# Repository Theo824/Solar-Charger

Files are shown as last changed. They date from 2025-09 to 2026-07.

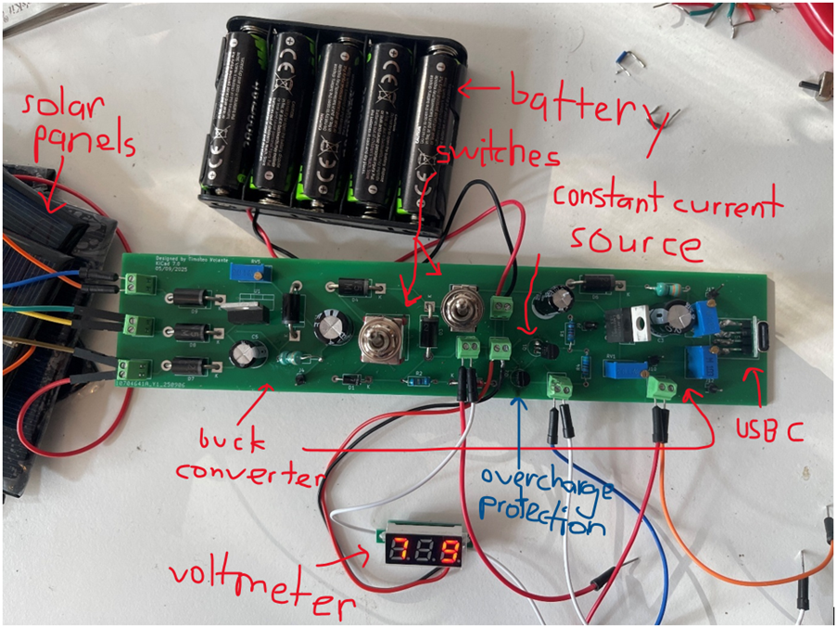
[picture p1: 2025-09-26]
PCB_Pics/solarCharger_assembled_PCB_diagramPic.png

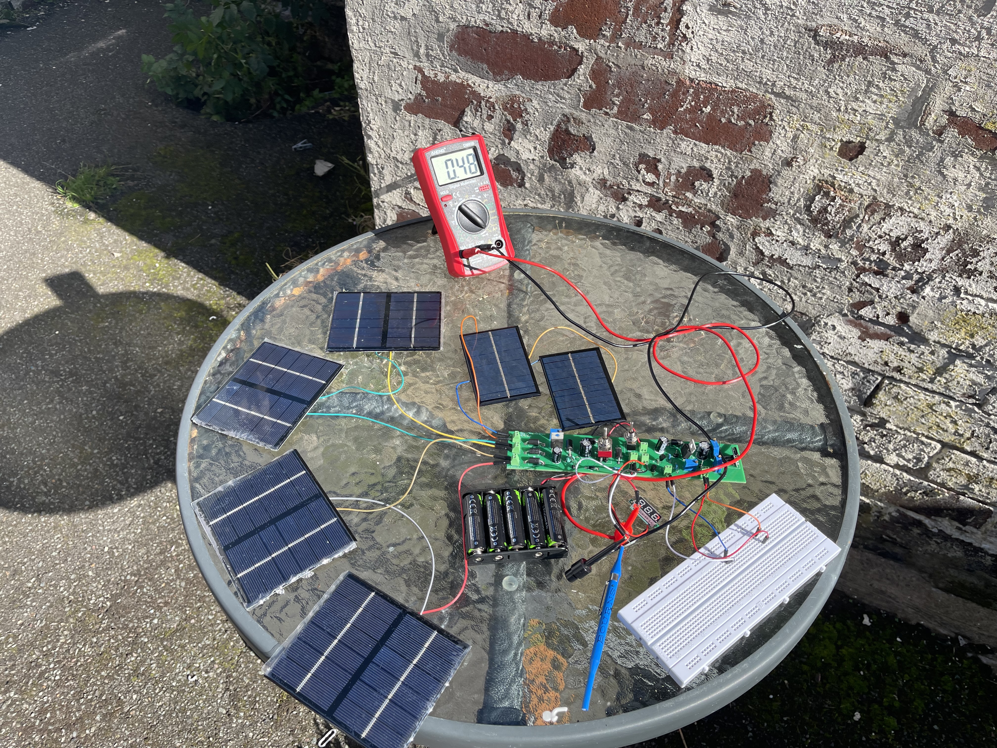
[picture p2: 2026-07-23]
Testing_Pics/NiMHBatteryCharging.jpg

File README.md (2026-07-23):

Designed and built a solar panel-powered constant-current charger for NiMH or NiCD batteries, or an iPhone, 
which can function as a power bank or be used in other devices.

The voltages are adjustable to accommodate any battery, and the solar panels are detachable through screw connectors.

Conceived the design concept centred around only two transistors. 
Researched the iPhone charging handshake protocol, modified the circuit in NI Multisim to correct functionality, 
and integrated it onto a 2-layer PCB using KiCad.

The charger delivered 5 W to the iPhone and 4 W to five AA NiMH batteries in series.
Once fully charged, the auto-cutoff reduced the charging current by 85.12% to 0.025C. 

In theory, the batteries could also charge an iPhone 12 Pro Max up to three times without the solar panels.

The LED display shows the battery voltage. 
To turn it to iPhone charging, turn the switches down; for NiMH charging, turn them up.

For more step-by-step information on the process or log of making this project, please look at solarCharger24-25_Logbook.pdf or solarCharger24-25_Logbook.docx: [Click here to view the Cloud File](https://1drv.ms/w/c/10176ce2d1328c94/IQDAm-Wb3D2zQ42p3uI7dwKKAQNEjcbpd-CYOFzZ3OIuXmA?e=BsMwEE)

Note: The descriptions are below their corresponding images.

sketchIdea

clearKiCadSchematic

solarChargerPCB_diagramPic

The PCB could be made significantly smaller by using smaller components, switching to surface-mount devices, 
and removing test components such as screw connectors. 

I did not use surface-mount devices because my inexpensive soldering kit cannot solder them precisely. 
Using only one buck converter is not feasible, since a 5 V output cannot charge 5 × AA NiMH batteries (5–7 V), 
lower battery voltages cannot charge an iPhone, and using more than 5 V with a single buck converter would damage the iPhone.

KiCadPic

KiCadPic3D

breadboardTest_iPhone

If you look closely, you can see the iPhone lightning symbol, which indicates charging. 
The power adapter could not give more than 0.53 A.



The graph above is the data gathered from testing the breadboard prototype on charging NiMH battery.
It indicates auto-cutoff at 7.25 V or 1.45 V each battery cell.

NiMHBatteryCharging

0.48 A is the charging current of the NiMH battery.

NiMH_PCB_CutOff

The graph above is the data gathered from testing the PCB prototype on charging NiMH battery. 
It indicates auto-cutoff at 7.33 V or 1.466 V each battery cell.

iPhone5WCharg

0.83 A is the recorded charging current of iPhone. This fluctuated around 1 A (5 W) throughout the testing.

iPhoneChargeGraph1

The graph above illustrates the charging speed in relation to the battery percentage. It roughly takes 5 minutes to increase it by 1%.

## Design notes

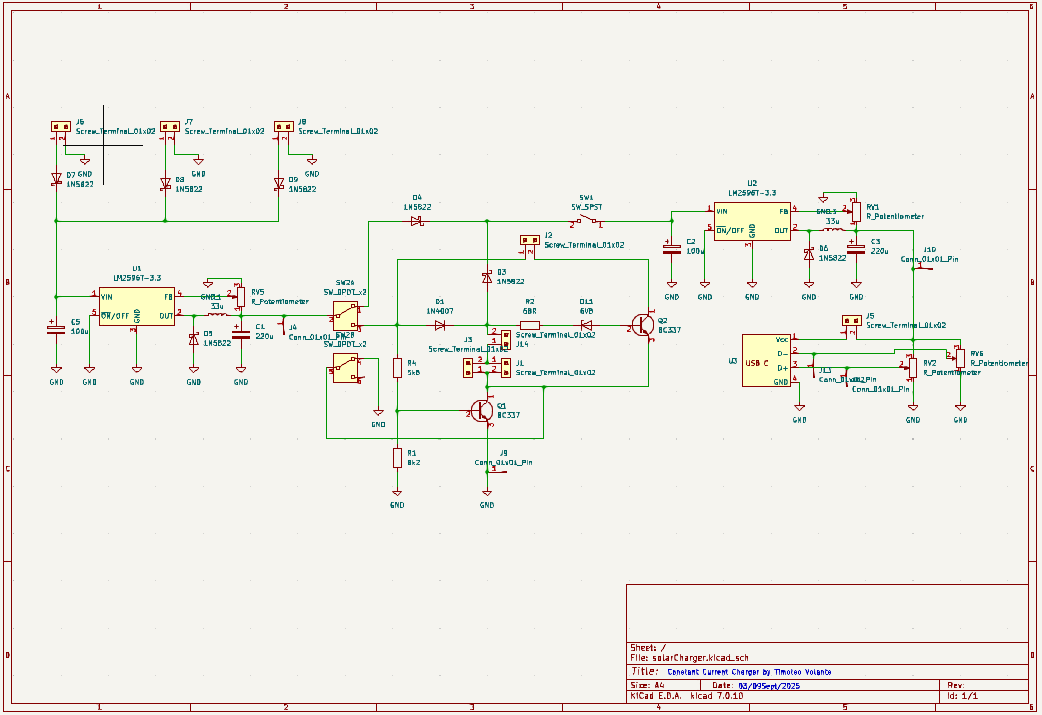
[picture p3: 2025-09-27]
PCB_Pics/clearKiCadSchematic.png

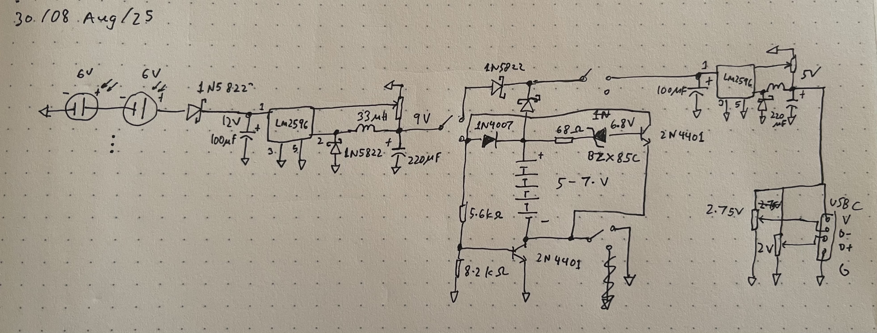
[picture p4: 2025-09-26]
PCB_Pics/sketchIdea.jpg

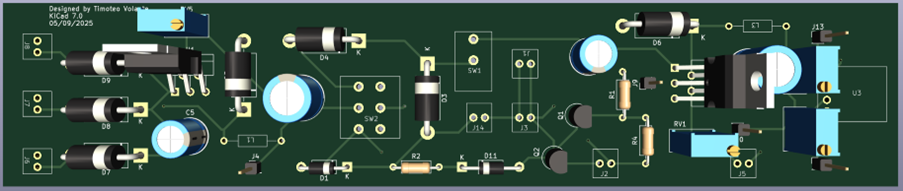
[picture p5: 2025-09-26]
PCB_Pics/KiCad_3D_Model_Pic.png

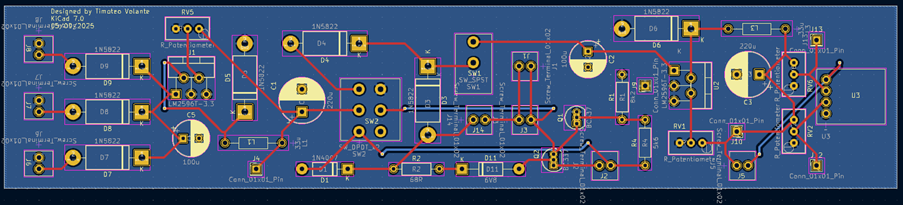
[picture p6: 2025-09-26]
PCB_Pics/KiCad_Layers_Pic.png

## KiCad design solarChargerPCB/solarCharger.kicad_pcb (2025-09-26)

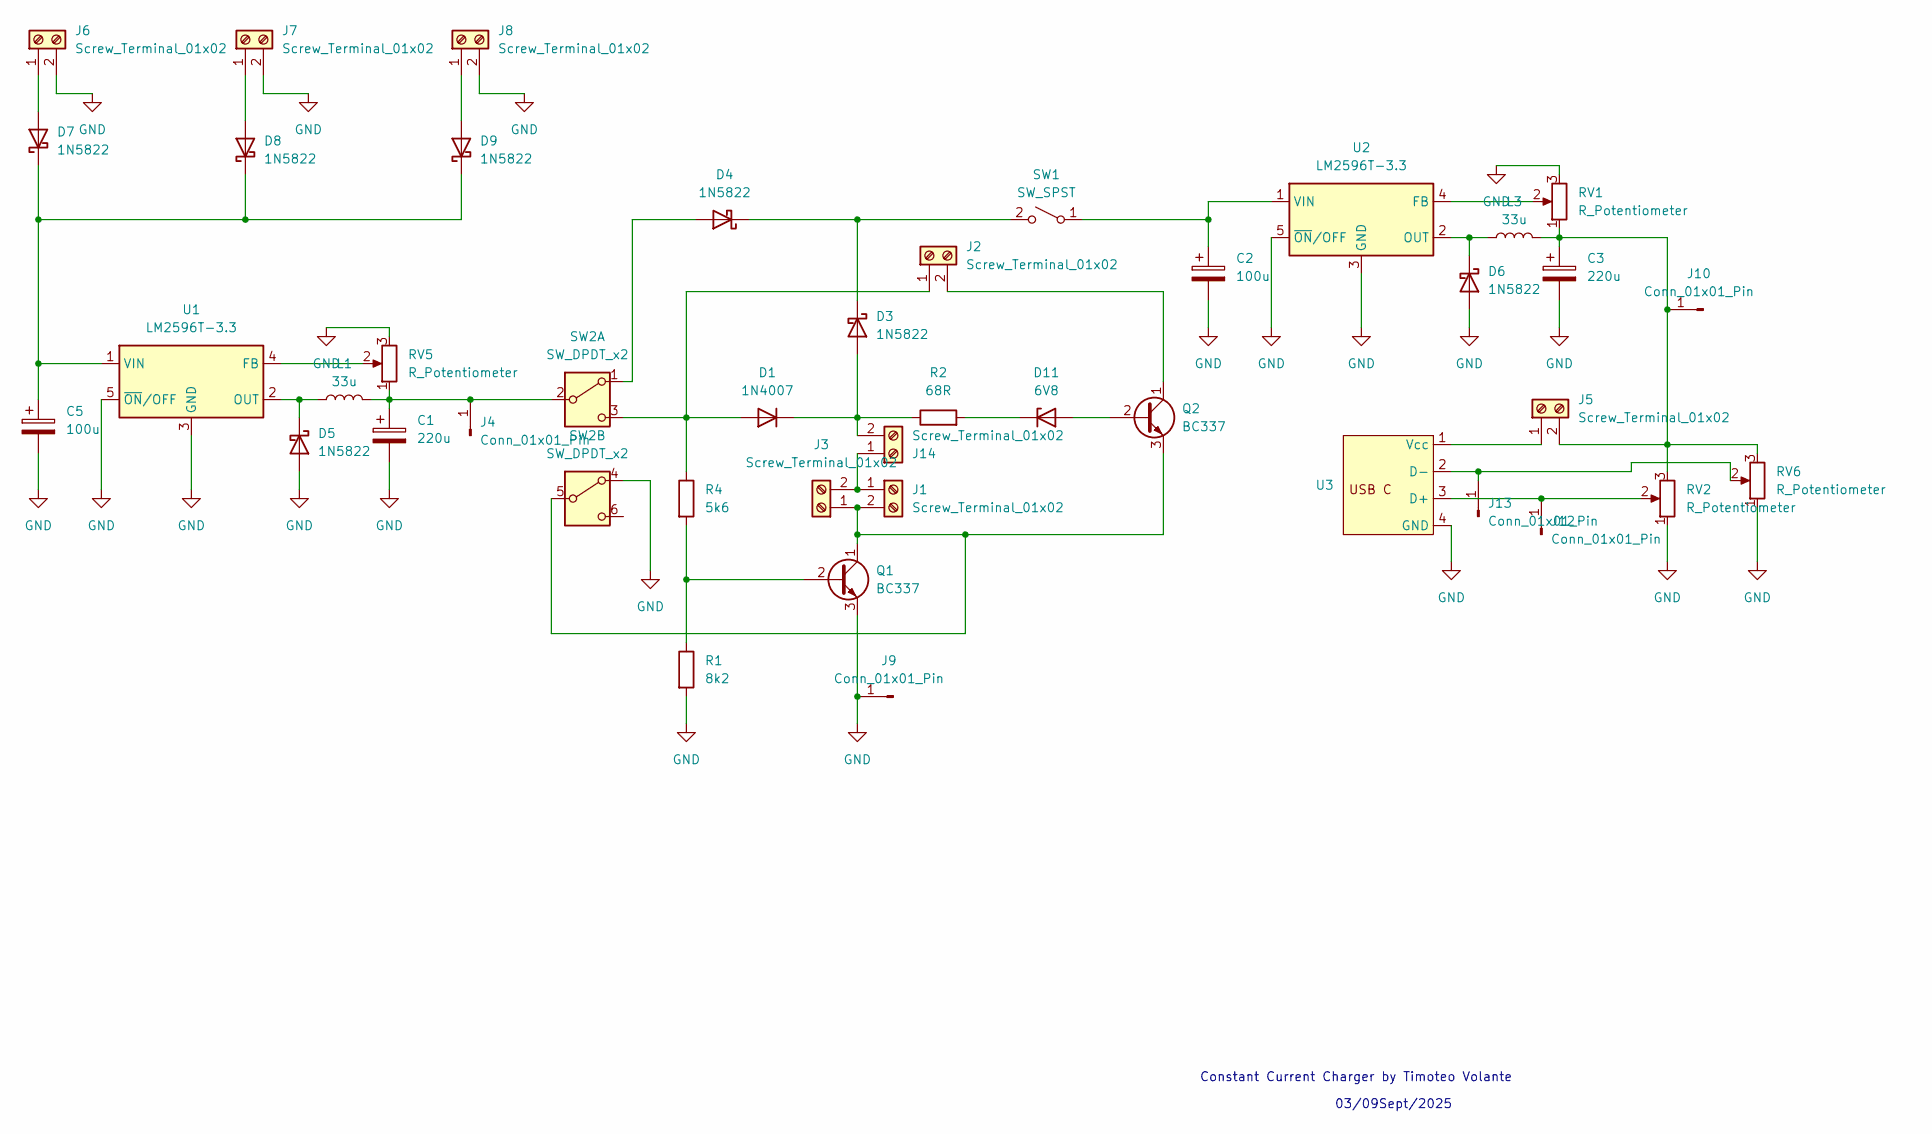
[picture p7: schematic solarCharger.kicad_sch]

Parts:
C1, C3: 220u; CP_Radial_D10.0mm_P5.00mm
C2, C5: 100u; CP_Radial_D8.0mm_P3.50mm
D1: 1N4007; D_DO-41_SOD81_P10.16mm_Horizontal
D3, D4, D5, D6, D7, D8, D9: 1N5822; D_DO-201AD_P15.24mm_Horizontal
D11: 6V8; D_DO-41_SOD81_P12.70mm_Horizontal
J1, J2, J3, J5, J6, J7, J8, J14: Screw_Terminal_01x02; 2_54mm_Pitch_Mount_Screw_Terminal_Connector
J4, J9, J10, J12, J13: Conn_01x01_Pin; PinHeader_1x01_P2.54mm_Vertical
L1, L3: 33u; inductor_L6mm_D2_3mm_W28mm
Q1, Q2: BC337; TO-92_Inline
R1: 8k2; R_Axial_DIN0207_L6.3mm_D2.5mm_P10.16mm_Horizontal
R2: 68R; R_Axial_DIN0207_L6.3mm_D2.5mm_P10.16mm_Horizontal
R4: 5k6; R_Axial_DIN0207_L6.3mm_D2.5mm_P10.16mm_Horizontal
RV1, RV2, RV5, RV6: R_Potentiometer; Potentiometer_Bourns_3296W_Vertical
SW1: SW_SPST; Toggle_SPST
SW2: SW_DPDT_x2; Toggle_DPDT
U1, U2: LM2596T-3.3; TO-220-5_P3.4x3.7mm_StaggerOdd_Lead3.8mm_Vertical
U3: USB_C_module

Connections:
GND: C1.2, C2.2, C3.2, C5.2, D5.2 (A), D6.2 (A), J6.2, J7.2, J8.2, J9.1, Q1.3 (E), R1.2, RV1.3, RV2.1, RV5.3, RV6.1, SW2.4 (A), U1.3 (GND), U1.5 (~ON/OFF), U2.3 (GND), U2.5 (~ON/OFF), U3.4 (GND)
unnamed: D1.2 (A), J2.1, R4.1, SW2.3 (C)
unnamed: D1.1 (K), D3.2 (A), J14.2, R2.1
unnamed: D3.1 (K), D4.1 (K), SW1.2 (B)
unnamed: D4.2 (A), SW2.1 (A)
unnamed: D5.1 (K), L1.1, U1.2 (OUT)
unnamed: D6.1 (K), L3.1, U2.2 (OUT)
unnamed: D7.2 (A), J6.1
unnamed: C5.1, D7.1 (K), D8.1 (K), D9.1 (K), U1.1 (VIN)
unnamed: D8.2 (A), J7.1
unnamed: D9.2 (A), J8.1
unnamed: D11.2 (A), Q2.2 (B)
unnamed: D11.1 (K), R2.2
unnamed: J1.1, J3.2, J14.1
unnamed: J1.2, J3.1, Q1.1 (C), Q2.3 (E), SW2.5 (B)
unnamed: J2.2, Q2.1 (C)
unnamed: C1.1, J4.1, L1.2, RV5.1, SW2.2 (B)
unnamed: J5.1, U3.1 (Vcc)
unnamed: C3.1, J5.2, J10.1, L3.2, RV1.1, RV2.3, RV6.3
unnamed: J12.1, RV2.2, U3.3 (D+)
unnamed: J13.1, RV6.2, U3.2 (D-)
unnamed: Q1.2 (B), R1.1, R4.2
unnamed: C2.1, SW1.1 (A), U2.1 (VIN)
unnamed: RV5.2, U1.4 (FB)
unnamed: RV1.2, U2.4 (FB)

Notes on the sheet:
Constant Current Charger by Timoteo Volante
03/09Sept/2025

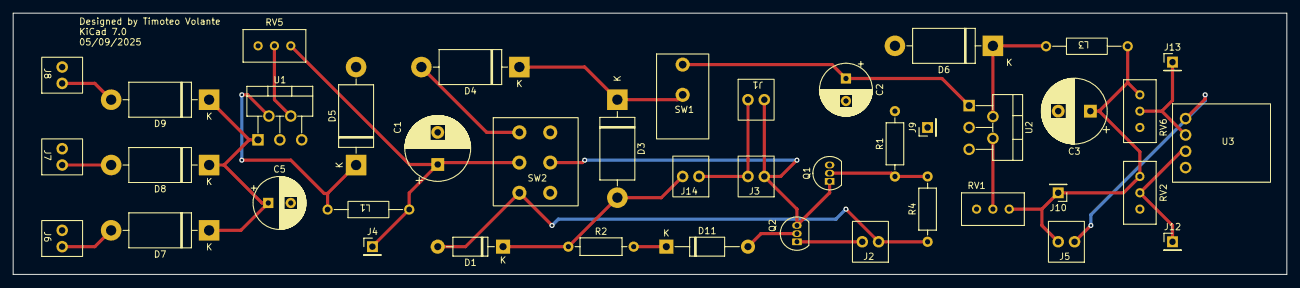
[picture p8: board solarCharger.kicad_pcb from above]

Board: 2 copper layers, 198.1 x 40.6 mm, 42 parts (0 on the bottom side), 25 nets.

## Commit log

2026-07-23 Rename KiCad_3D_Model_Pic.png to PCB_Pics/KiCad_3D_Model_Pic.png
    Move the file.
2026-07-23 Rename KiCad_Layers_Pic.png to PCB_Pics/KiCad_Layers_Pic.png
    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
2026-07-23 Rename clearKiCadSchematic.png to PCB_Pics/clearKiCadSchematic.png
    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
2026-07-23 Rename solarChargerPCB_diagramPic.png to PCB_Pics/solarChargerPCB_diagramPic.png
    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
2026-07-23 Rename solarChargerPCBpic.jpg to PCB_Pics/solarChargerPCBpic.jpg
    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
